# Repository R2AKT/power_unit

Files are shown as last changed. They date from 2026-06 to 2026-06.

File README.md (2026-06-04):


License addendum - https://github.com/R2AKT/power_unit/blob/main/Addendum.txt
# power_unit
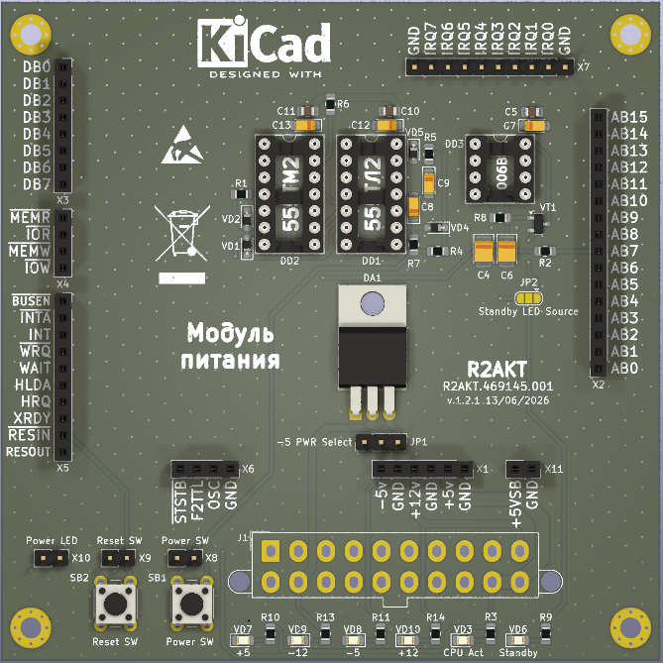
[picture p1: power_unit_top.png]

Power control unit. For Mega-80 (Mega-580) DIY 8-bit micro-computer - https://github.com/R2AKT/Mega-80.
ATX PSU control based on 'ISA 8-bit Backplane' (https://github.com/skiselev/isa8_backplane).

Status - Tested.

Плата питания. Для самодельной 8-битной микро-ЭВМ - https://github.com/R2AKT/Mega-80.
Управление блоком питания ATX на основе 'ISA 8-bit Backplane' (https://github.com/skiselev/isa8_backplane).

Статус - Проверено.

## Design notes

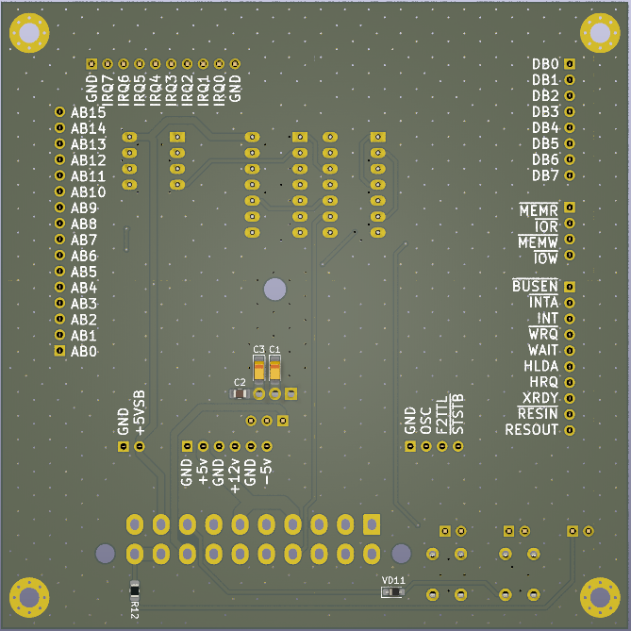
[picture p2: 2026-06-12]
power_unit_btn.png

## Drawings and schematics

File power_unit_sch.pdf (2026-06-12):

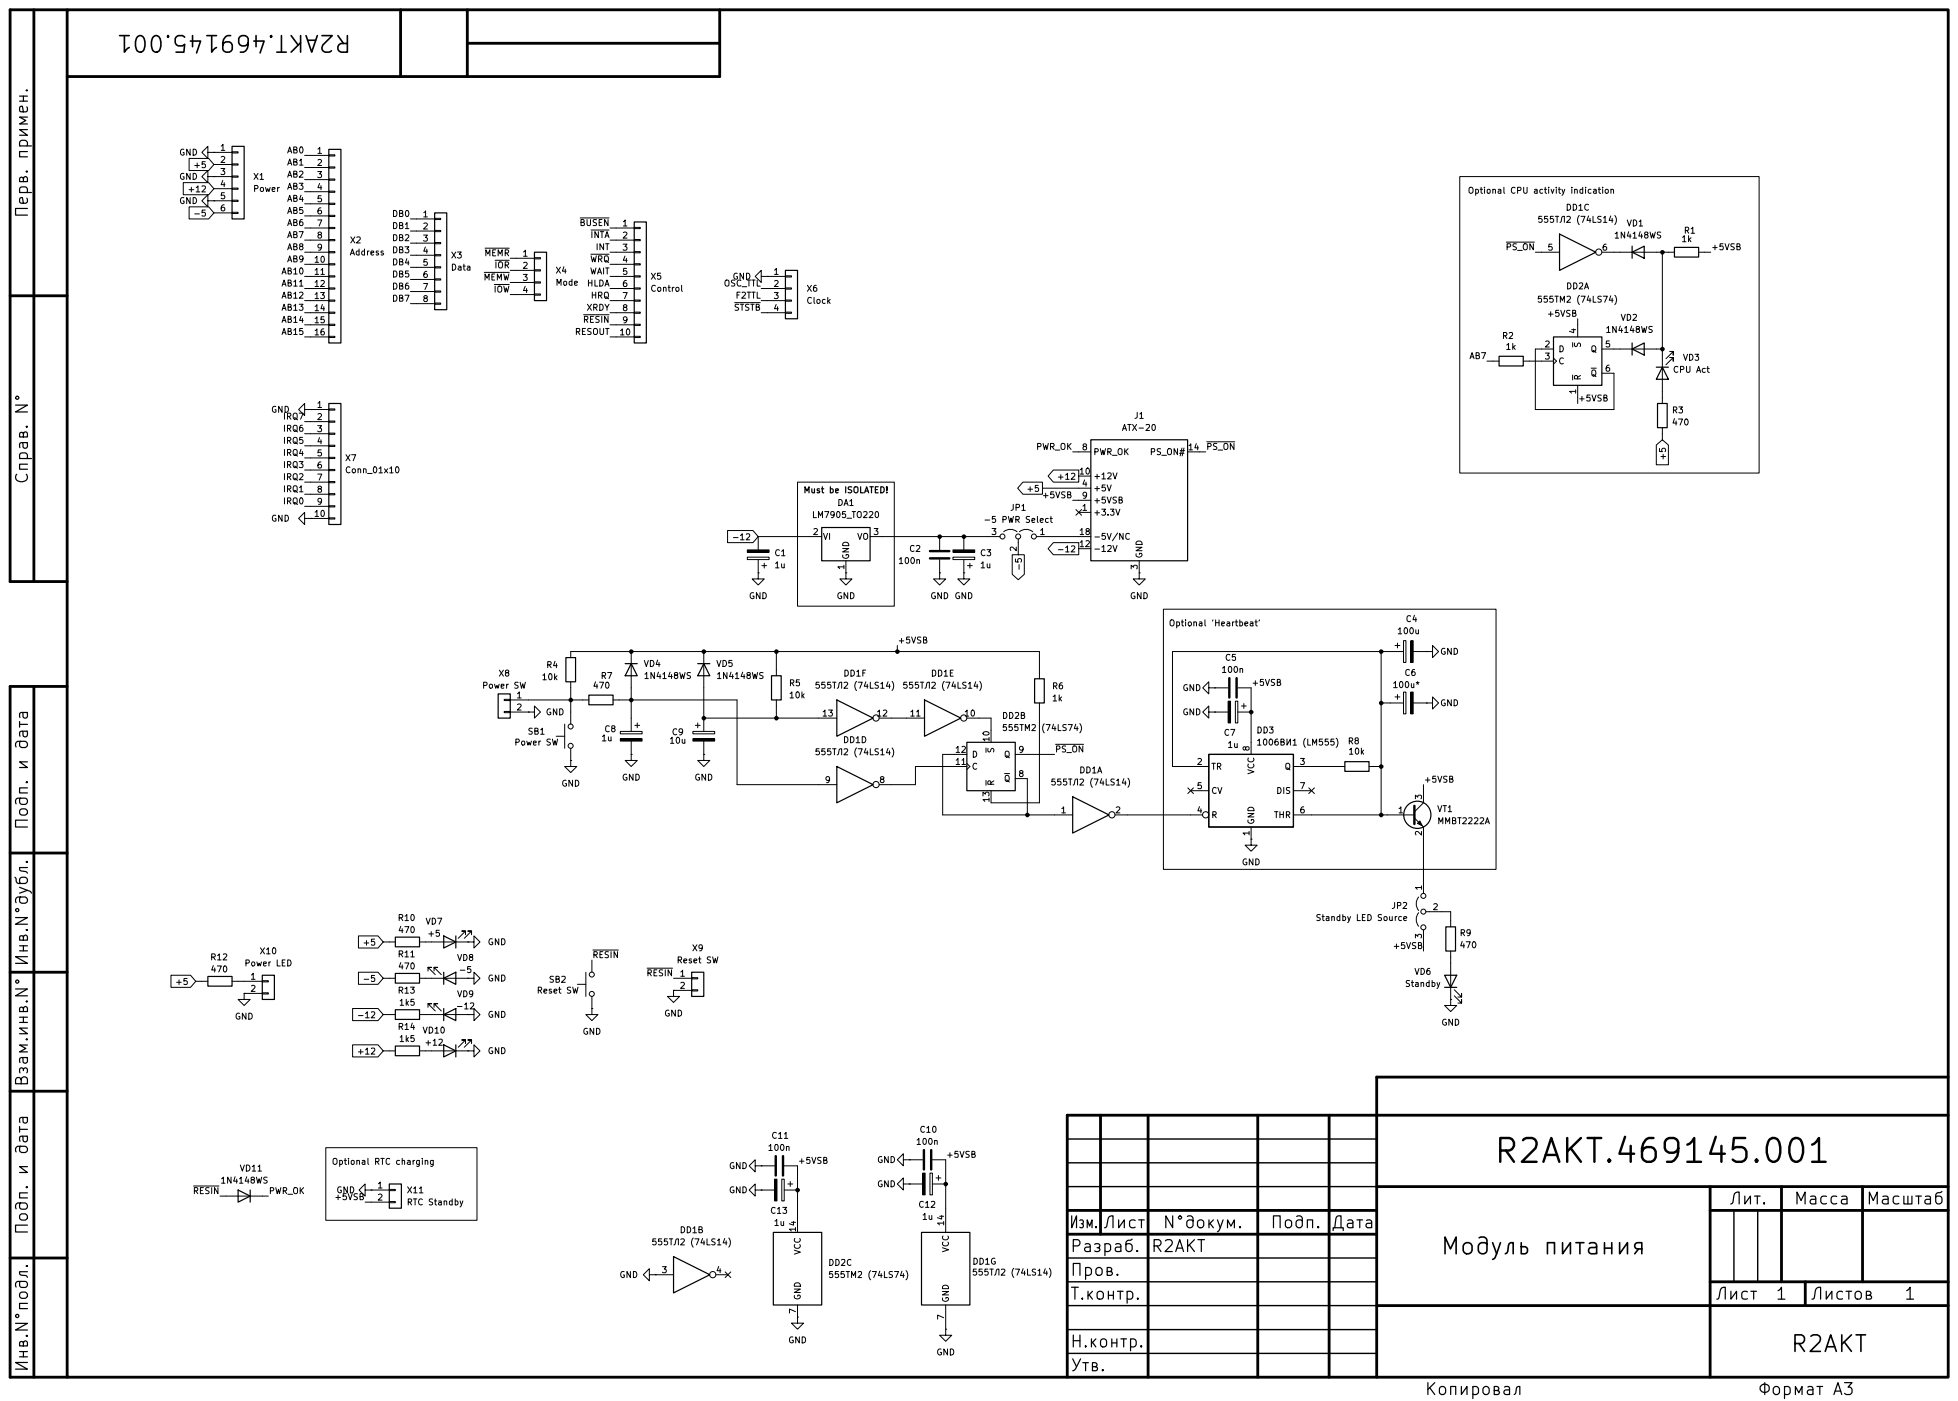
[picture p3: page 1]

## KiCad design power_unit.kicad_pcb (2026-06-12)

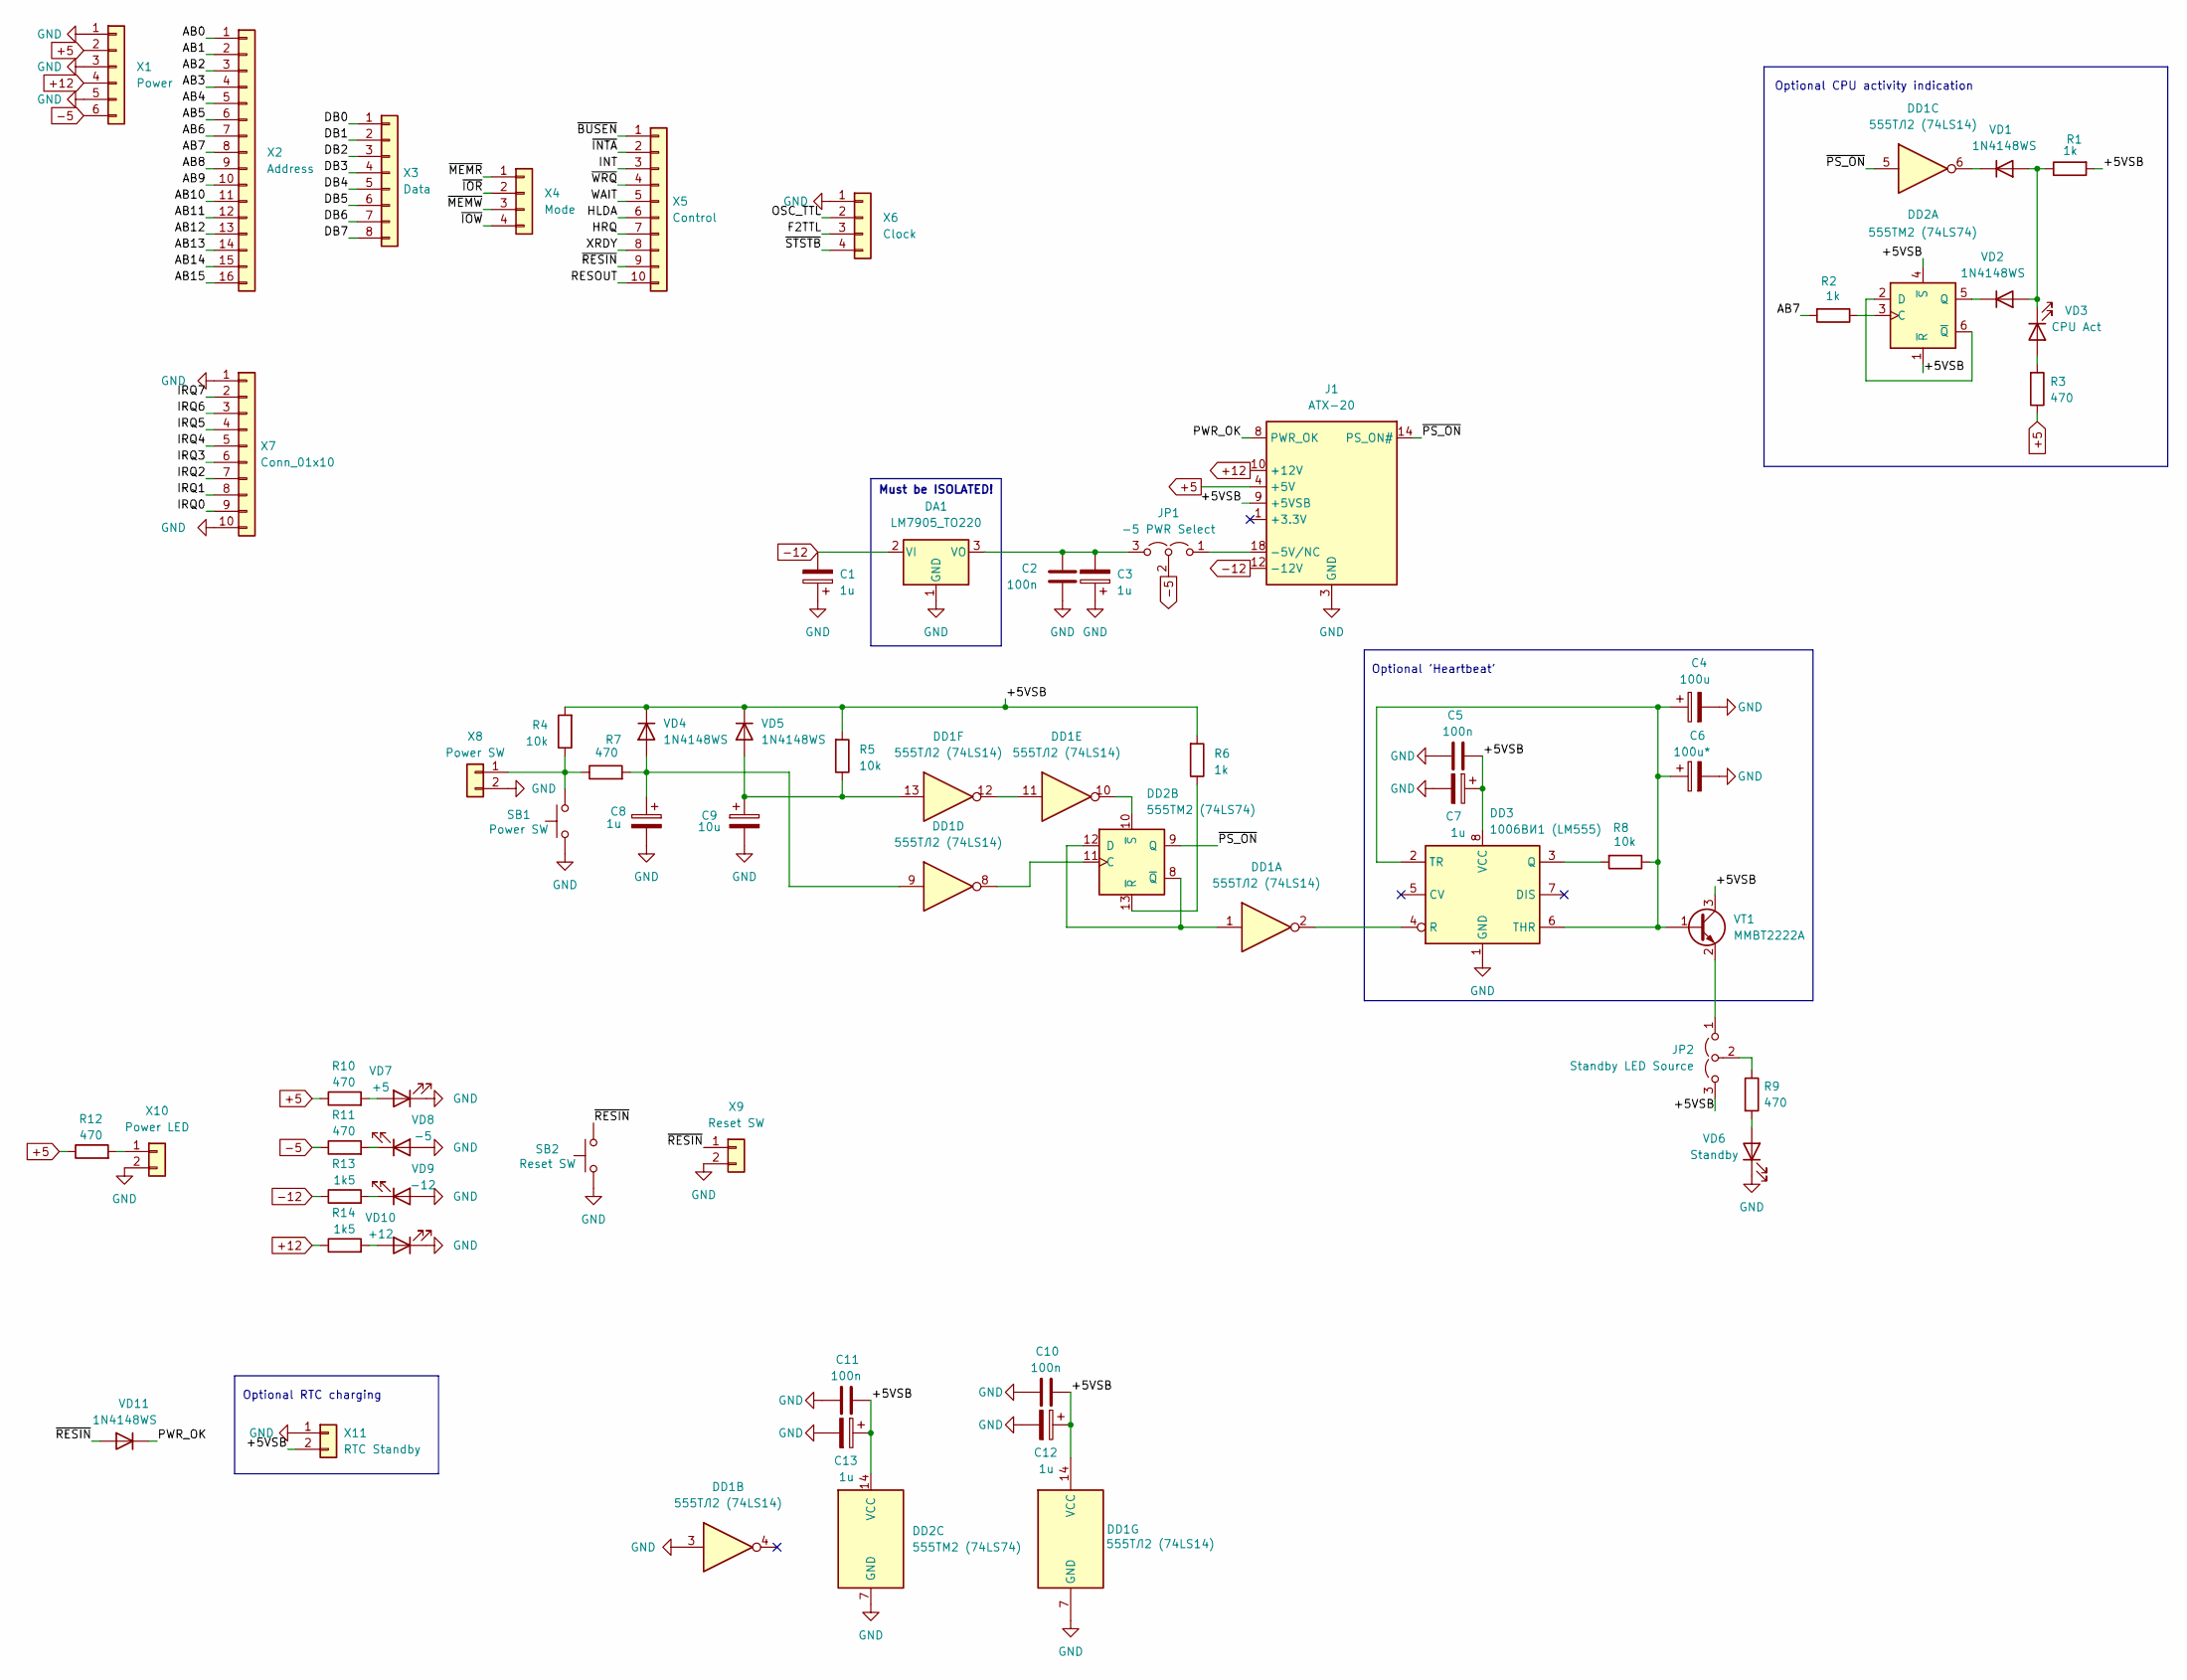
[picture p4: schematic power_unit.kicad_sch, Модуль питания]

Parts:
C1, C3, C7, C8, C12, C13: 1u; CP_EIA-3216-18_Kemet-A_Pad1.58x1.35mm_HandSolder
C2, C5, C10, C11: 100n; C_0805_2012Metric_Pad1.18x1.45mm_HandSolder
C4: 100u; CP_EIA-3528-21_Kemet-B_Pad1.50x2.35mm_HandSolder
C6: 100u*; CP_EIA-3528-21_Kemet-B_Pad1.50x2.35mm_HandSolder
C9: 10u; CP_EIA-3216-18_Kemet-A_Pad1.58x1.35mm_HandSolder
DA1: LM7905_TO220; TO-220-3_Horizontal_TabDown
DD1: 555ТЛ2 (74LS14); DIP-14_W7.62mm_Socket_LongPads
DD2: 555ТМ2 (74LS74); DIP-14_W7.62mm_Socket_LongPads
DD3: 1006ВИ1 (LM555); DIP-8_W7.62mm_Socket_LongPads
J1: ATX-20
JP1: -5 PWR Select; PinHeader_1x03_P2.54mm_Vertical
JP2: Standby LED Source; SolderJumper-3_P1.3mm_Open_RoundedPad1.0x1.5mm
R1, R2, R6: 1k; R_0805_2012Metric_Pad1.20x1.40mm_HandSolder
R3, R7, R9, R10, R11, R12: 470; R_0805_2012Metric_Pad1.20x1.40mm_HandSolder
R4, R5, R8: 10k; R_0805_2012Metric_Pad1.20x1.40mm_HandSolder
R13, R14: 1k5; R_0805_2012Metric_Pad1.20x1.40mm_HandSolder
SB1: Power SW; SW_PUSH_6mm
SB2: Reset SW; SW_PUSH_6mm
VD1, VD2, VD4, VD5, VD11: 1N4148WS; D_SOD-323_HandSoldering
VD3: CPU Act; LED_0805_2012Metric_Pad1.15x1.40mm_HandSolder
VD6: Standby; LED_0805_2012Metric_Pad1.15x1.40mm_HandSolder
VD7: +5; LED_0805_2012Metric_Pad1.15x1.40mm_HandSolder
VD8: -5; LED_0805_2012Metric_Pad1.15x1.40mm_HandSolder
VD9: -12; LED_0805_2012Metric_Pad1.15x1.40mm_HandSolder
VD10: +12; LED_0805_2012Metric_Pad1.15x1.40mm_HandSolder
VT1: MMBT2222A; SOT-23
X1: Power; PinSocket_1x06_P2.54mm_Vertical
X2: Address; PinSocket_1x16_P2.54mm_Vertical
X3: Data; PinSocket_1x08_P2.54mm_Vertical
X4: Mode; PinSocket_1x04_P2.54mm_Vertical
X5: Control; PinSocket_1x10_P2.54mm_Vertical
X6: Clock; PinSocket_1x04_P2.54mm_Vertical
X7: Conn_01x10; PinHeader_1x10_P2.54mm_Vertical
X8: Power SW; PinHeader_1x02_P2.54mm_Vertical
X9: Reset SW; PinHeader_1x02_P2.54mm_Vertical
X10: Power LED; PinHeader_1x02_P2.54mm_Vertical
X11: RTC Standby; PinSocket_1x02_P2.54mm_Vertical

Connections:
+5: J1.4 (+5V), J1.6 (+5V), J1.19 (+5V), J1.20 (+5V), R3.1, R10.1, R12.1, X1.2
+12: J1.10 (+12V), R14.1, X1.4
-5: JP1.2 (C), R11.1, X1.6
-12: C1.2, DA1.2 (VI), J1.12 (-12V), R13.1
/+5VSB: C5.1, C7.1, C10.1, C11.1, C12.1, C13.1, DD1.14 (VCC), DD2.1 (~R), DD2.4 (~S), DD2.14 (VCC), DD3.8 (VCC), J1.9 (+5VSB), JP2.3 (B), R1.2, R4.2, R5.2, R6.2, VD4.1 (K), VD5.1 (K), VT1.3 (C), X11.2
/AB0: X2.1
/AB1: X2.2
/AB2: X2.3
/AB3: X2.4
/AB4: X2.5
/AB5: X2.6
/AB6: X2.7
/AB7: R2.2, X2.8
/AB8: X2.9
/AB9: X2.10
/AB10: X2.11
/AB11: X2.12
/AB12: X2.13
/AB13: X2.14
/AB14: X2.15
/AB15: X2.16
/DB0: X3.1
/DB1: X3.2
/DB2: X3.3
/DB3: X3.4
/DB4: X3.5
/DB5: X3.6
/DB6: X3.7
/DB7: X3.8
/F2TTL: X6.3
/HLDA: X5.6
/HRQ: X5.7
/INT: X5.3
/IRQ0: X7.9
/IRQ1: X7.8
/IRQ2: X7.7
/IRQ3: X7.6
/IRQ4: X7.5
/IRQ5: X7.4
/IRQ6: X7.3
/IRQ7: X7.2
/OSC_TTL: X6.2
/PWR_OK: J1.8 (PWR_OK), VD11.1 (K)
/RESOUT: X5.10
/WAIT: X5.5
/XRDY: X5.8
/~BUSEN: X5.1
/~INTA: X5.2
/~IOR: X4.2
/~IOW: X4.4
/~MEMR: X4.1
/~MEMW: X4.3
/~PS_ON: DD1.5, DD2.9 (Q), J1.14 (PS_ON#)
/~RESIN: SB2.2, VD11.2 (A), X5.9, X9.1
/~STSTB: X6.4
/~WRQ: X5.4
GND: C1.1, C2.2, C3.1, C4.2, C5.2, C6.2, C7.2, C8.2, C9.2, C10.2, C11.2, C12.2, C13.2, DA1.1 (GND), DD1.3, DD1.7 (GND), DD2.7 (GND), DD3.1 (GND), J1.3 (GND), J1.5 (GND), J1.7 (GND), J1.13 (GND), J1.15 (GND), J1.16 (GND), J1.17 (GND), SB1.1, SB2.1, VD6.1 (K), VD7.1 (K), VD8.2 (A), VD9.2 (A), VD10.1 (K), X1.1, X1.3, X1.5, X6.1, X7.1, X7.10, X8.2, X9.2, X10.2, X11.1; also elsewhere on the board
unnamed: C2.1, C3.2, DA1.3 (VO), JP1.3 (B)
unnamed: DD1.11, DD1.12
unnamed: DD2.3 (C), R2.1
unnamed: DD2.2 (D), DD2.6 (~Q)
unnamed: DD2.5 (Q), VD2.1 (K)
unnamed: DD1.8, DD2.11 (C)
unnamed: DD1.1, DD2.8 (~Q), DD2.12 (D)
unnamed: DD2.13 (~R), R6.1
unnamed: DD1.10, DD2.10 (~S)
unnamed: DD3.3 (Q), R8.2
unnamed: DD1.2, DD3.4 (R)
unnamed: C4.1, C6.1, DD3.2 (TR), DD3.6 (THR), R8.1, VT1.1 (B)
unnamed: J1.18 (-5V/NC), JP1.1 (A)
unnamed: JP2.1 (A), VT1.2 (E)
unnamed: JP2.2 (C), R9.1
unnamed: R1.1, VD1.2 (A), VD2.2 (A), VD3.1 (K)
unnamed: DD1.6, VD1.1 (K)
unnamed: R3.2, VD3.2 (A)
unnamed: C8.1, DD1.9, R7.2, VD4.2 (A)
unnamed: C9.1, DD1.13, R5.1, VD5.2 (A)
unnamed: R9.2, VD6.2 (A)
unnamed: R10.2, VD7.2 (A)
unnamed: R11.2, VD8.1 (K)
unnamed: R13.2, VD9.1 (K)
unnamed: R14.2, VD10.2 (A)
unnamed: R4.1, R7.1, SB1.2, X8.1
unnamed: R12.2, X10.1

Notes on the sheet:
Optional 'Heartbeat'
Optional CPU activity indication
Must be ISOLATED!
Optional RTC charging

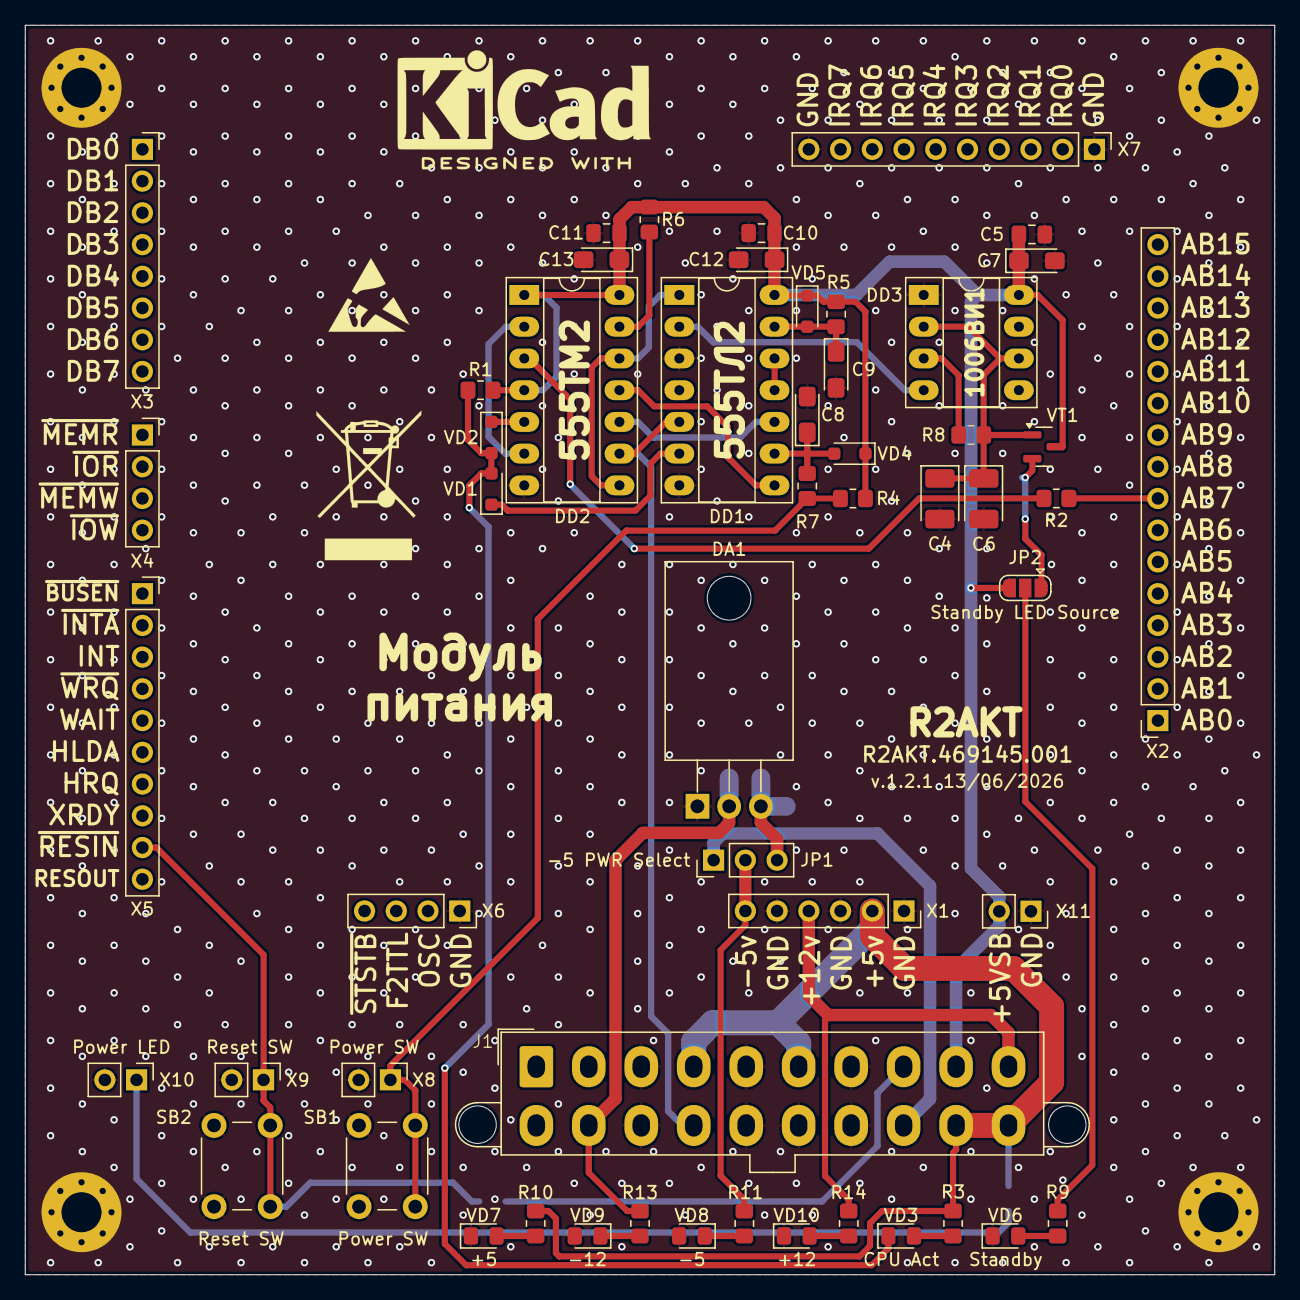
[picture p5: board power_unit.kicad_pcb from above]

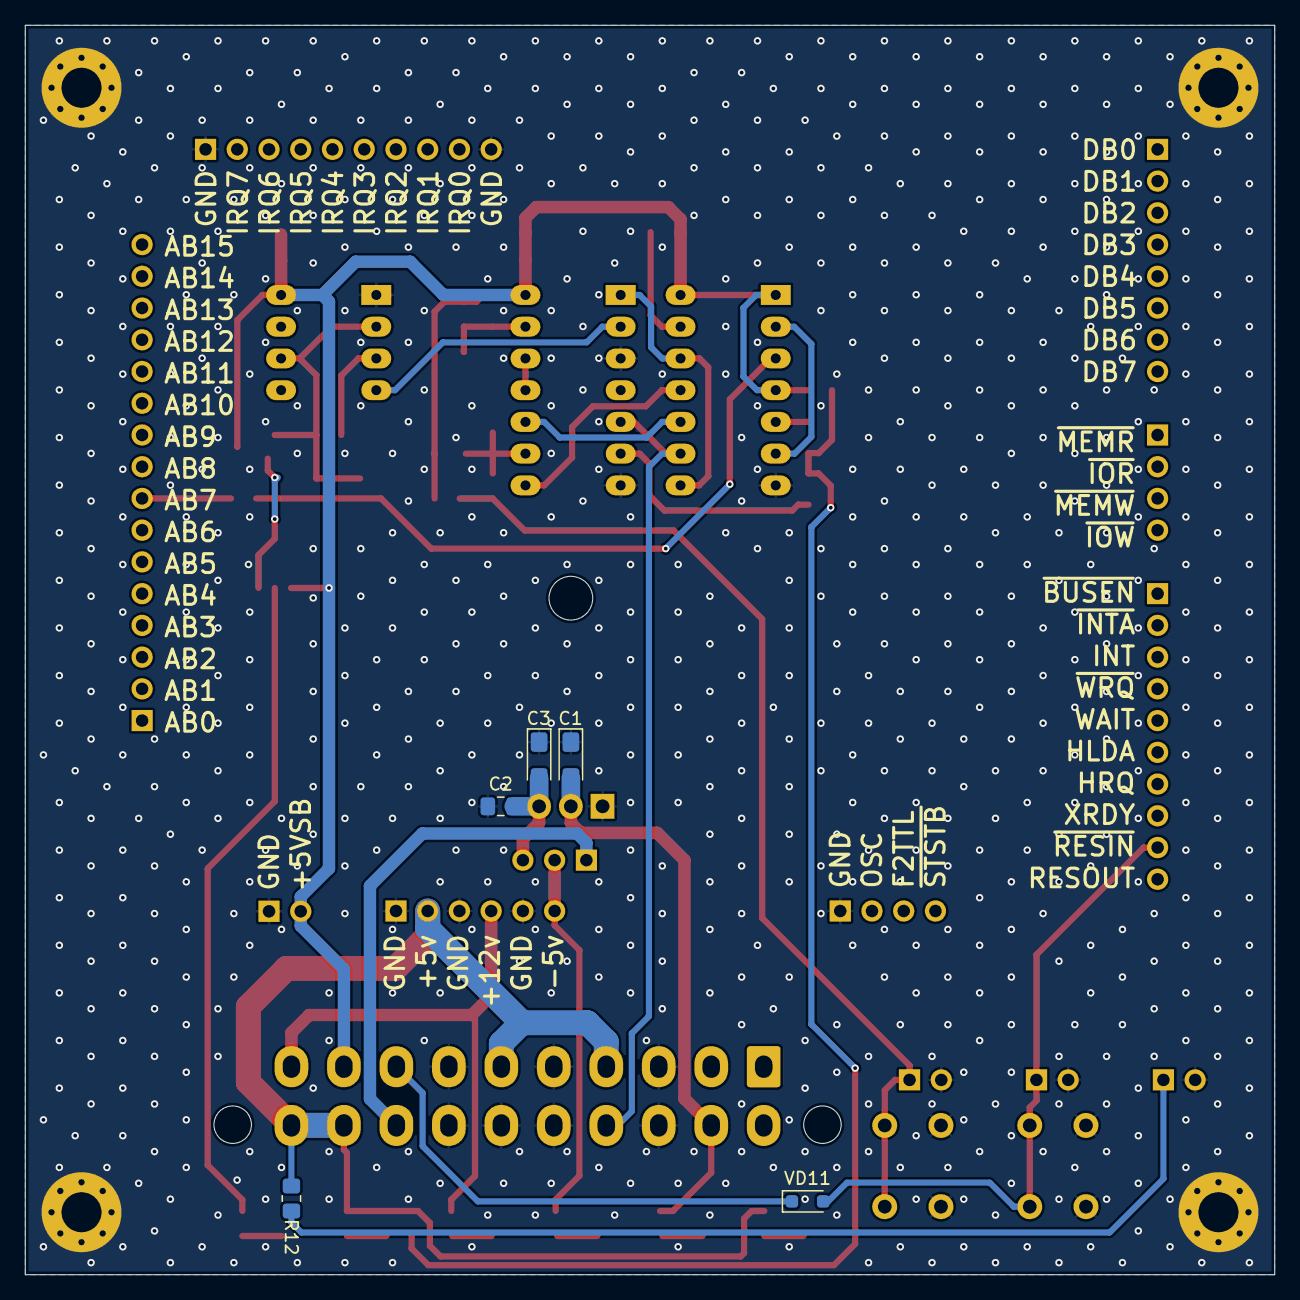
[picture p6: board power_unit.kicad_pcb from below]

Board: 2 copper layers, 100.0 x 100.0 mm, 63 parts (5 on the bottom side), 37 nets.

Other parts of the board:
H1, H2, H3, H4: MountingHole_Pad; MountingHole_3.2mm_M3_Pad_Via

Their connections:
GND: H1.1, H2.1, H3.1, H4.1; also elsewhere on the board

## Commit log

2026-03-23 Add files via upload
    Removed +5V LVR, added connection 'PG_OK' to 'ResIn'.
    Удалён линейный стабилизатор +5В, добавлено соединение 'PG_OK' с 'ResIn'.
    [power_unit.kicad_pcb, power_unit.kicad_sch]
2026-06-12 Update
    Fix footprint's, change optional shematic, add comment's
    [power_unit.kicad_pcb, power_unit.kicad_sch, psu.kicad_sch]

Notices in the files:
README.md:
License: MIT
